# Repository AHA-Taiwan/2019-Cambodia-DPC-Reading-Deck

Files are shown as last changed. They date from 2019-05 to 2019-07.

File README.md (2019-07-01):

# 2019-Cambodia-DPC-Reading-Deck 柬埔寨教室改造設計
>Humanitarian Architecture in Cambodia<br/>
>以人道建築宗旨出發，由台灣交通大學服務學習中心、全球公民教育中心發起，與柬埔寨DPC小學、家扶中心合作規劃。使用自然材料、就地取材為原則，由交大建築所策劃義築設計、大安高工進行實作測試與志工培訓，設計規劃一個可容納約30名師生使用，離地抬高20至200公分並錯落配置的木鐵混構閱讀及活動平台。<br/>

## 基地環境：<br/>
位於柬泰邊境聚落，木材使用未加工原木，設計時宜需注意材料含濕變形，以及後續防潮防蝕保護等。<br/>
* 基地環境氣象資料：http://worldweather.wmo.int/tc/home.html <br/>
* 氣象觀測歷史紀錄：http://worldweather.wmo.int/tc/city.html?cityId=347 <br/>
* Google Map 位置：https://goo.gl/maps/Xri239yRok2xkyNN6  <br/>

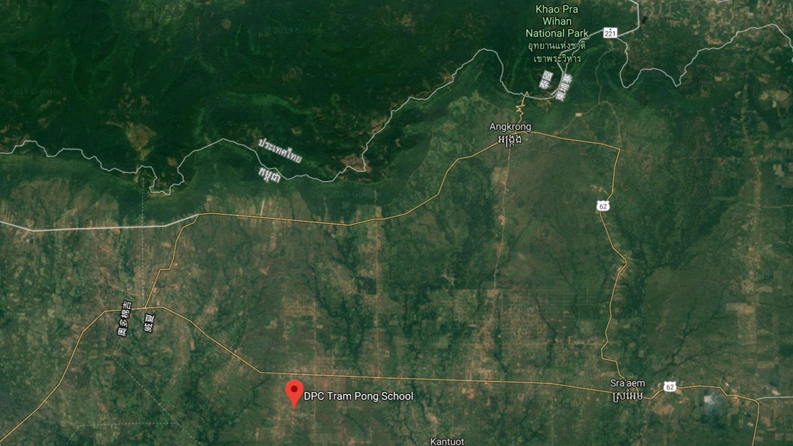
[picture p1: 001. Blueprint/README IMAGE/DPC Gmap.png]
Google Map

***
## 專案介紹：<br/>
* 主要建材：方鐵管[7.5x7.5x600cm(厚1.5mm)]、扁鐵管[4x8x600cm(厚1.5mm)]、原木板[2x25x400cm]、柬埔寨紅磚[8x8x17.5cm]等。
* 初勘簡介［影像紀錄］：https://reurl.cc/dkb1D
* 設計概述［影像紀錄］：https://reurl.cc/yNbDE
* 臉書紀錄：https://www.facebook.com/nctuasean/ 
* 數位模型［整體建物3D］：https://skfb.ly/6KQvW<br/>
* 數位模型［木柱露出3D］：https://skfb.ly/6KQwq<br/>
* 數位模型［鋼構平台3D］：https://skfb.ly/6KQw9<br/>
* 數位模型［主梁未轉3D］：https://skfb.ly/6LGSy<br/>
* 數位模型［最終定案3D］：https://skfb.ly/6LHYw<br/>

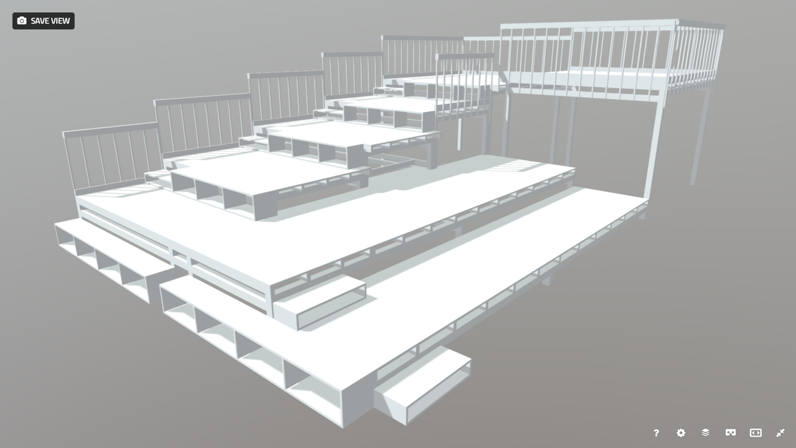
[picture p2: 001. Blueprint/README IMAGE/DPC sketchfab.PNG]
3D Model

<br/>
<br/>
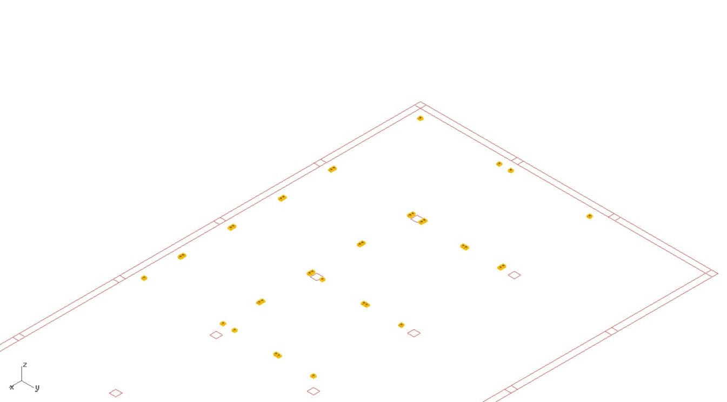
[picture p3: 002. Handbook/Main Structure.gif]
Main 20Structure.gif

<br/>
<br/>
***
## 如何達成合作建造：<br/>
* 請參閱［初次合作建造就上手 Collab-Const-Quick-Guide］：<br/>
https://github.com/AHA-Taiwan/Collab-Const-Quick-Guide/wiki <br/>
***
## 確保工作安全：<br/>
* 請參閱［合作建造-安全規範 Collab-Const-Safety］：<br/>
https://github.com/AHA-Taiwan/Collab-Const-Safety/wiki <br/>
***
## 探索合作資源：<br/>
* 請參閱［合作建造-資源探索 Collab-Const-Source］：<br/>
https://github.com/AHA-Taiwan/Collab-Const-Source/wiki <br/>
***
## 取得建造知識：<br/>
* 關於一般的常用構造技術（Techniques），請參閱［合作建造-學習知識 Collab-Const-Learning］：<br/>
https://github.com/AHA-Taiwan/Collab-Const-Learning/wiki <br/>
* 關於本案的特殊構築技術（Tectonic）， 請參閱［本案資料夾 002. Handbook］：<br/>
https://github.com/AHA-Taiwan/2019-Cambodia-DPC-Reading-Deck/tree/master/002.%20Handbook <br/>
***

> #### 歡迎參與專案開發，Branch合併可向專案管理者提出請求

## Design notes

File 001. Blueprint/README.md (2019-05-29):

CAD & 3D Simulation
更新設計圖請使用：

日期為檔名(ex:設計圖20190524.001) 
請在更新資料後於Commit changes做註解(ex:新增空心磚；修改柱位；刪除盪鞦韆設計)

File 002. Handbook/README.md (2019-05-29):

Handbook
更新施工手冊圖資請使用：

日期為檔名(ex:施工手冊 20190524.001)<br/>
請在更新資料後於Commit changes做註解(ex:新增空心磚；修改柱位；刪除盪鞦韆設計)

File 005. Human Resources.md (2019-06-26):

# 專業者佈局與人力成本紀錄 
主要紀錄整體施工過程中，專業者、準專業者、非專業者於不同工項所花費時數，從中可間接推估建造施工人力經費及時間成本。
專業者M、準專業者P、非專業者N，當地人加註C

## 一、鐵構施工
|人力編碼|當地人|工作總時數(hrs)|請工|換工|志工|
|:-:|:-:|:-:|:-:|:-:|:-:|
|MC01 |V |24 |V | |  |
|MC02 |V |24 |V | |  |
|MC02 |V |24 |V | |  |
|M01 | |16 | | |V |
|M02 | |16 | | |V |
|P01 | |16 | | |V |
|P02 | |16 | | |V |
***
## 二、矮牆砌磚
|人力編碼|當地人|工作總時數(hrs)|請工|換工|志工|
|:-:|:-:|:-:|:-:|:-:|:-:|
|M01 | |16 | | |V |
|P01 | |24 | | |V |
|P02 | |08 | | |V |
|N01 | |08 | | |V |
|N02 | |08 | | |V |
***
## 三、木地板加工
|人力編碼|當地人|工作總時數(hrs)|請工|換工|志工|
|:-:|:-:|:-:|:-:|:-:|:-:|
|M01 | |16 | | |V |
|P01 | |24 | | |V |
|P02 | |08 | | |V |
|N01 | |08 | | |V |
|N02 | |08 | | |V |
***
## 四、木扶手施工
|人力編碼|當地人|工作總時數(hrs)|請工|換工|志工|
|:-:|:-:|:-:|:-:|:-:|:-:|
|M01 | |16 | | |V |
|P01 | |24 | | |V |
|P02 | |08 | | |V |
|N01 | |08 | | |V |
|N02 | |08 | | |V |
***
## 五、木椅板固定於矮牆
|人力編碼|當地人|工作總時數(hrs)|請工|換工|志工|
|:-:|:-:|:-:|:-:|:-:|:-:|
|M01 | |16 | | |V |
|P01 | |24 | | |V |
|P02 | |08 | | |V |
|N01 | |08 | | |V |
|N02 | |08 | | |V |
***
## 六、木地板固定於受釘梁
|人力編碼|當地人|工作總時數(hrs)|請工|換工|志工|
|:-:|:-:|:-:|:-:|:-:|:-:|
|M01 | |16 | | |V |
|P01 | |24 | | |V |
|P02 | |08 | | |V |
|N01 | |08 | | |V |
|N02 | |08 | | |V |
***
## 七、木扶手固定於主梁
|人力編碼|當地人|工作總時數(hrs)|請工|換工|志工|
|:-:|:-:|:-:|:-:|:-:|:-:|
|M01 | |16 | | |V |
|P01 | |24 | | |V |
|P02 | |08 | | |V |
|N01 | |08 | | |V |
|N02 | |08 | | |V |
***
## 八、木地板收尾封邊
|人力編碼|當地人|工作總時數(hrs)|請工|換工|志工|
|:-:|:-:|:-:|:-:|:-:|:-:|
|M01 | |16 | | |V |
|P01 | |24 | | |V |
|P02 | |08 | | |V |
|N01 | |08 | | |V |
|N02 | |08 | | |V |
***
## 九、木書櫃施工
|人力編碼|當地人|工作總時數(hrs)|請工|換工|志工|
|:-:|:-:|:-:|:-:|:-:|:-:|
|M01 | |16 | | |V |
|P01 | |24 | | |V |
|P02 | |08 | | |V |
|N01 | |08 | | |V |
|N02 | |08 | | |V |
***

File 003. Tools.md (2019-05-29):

# 工具清單與故障維修紀錄 
主要紀錄整體施工過程中，所有使用之工具名稱、規格、數量、單位、廠牌、工具來源、維修紀錄(日期)等，從中可間接推估工具數量及機具購買或租借成本。

## 安全工具 
|編碼|工具名稱|規格|數量|單位|廠牌|工具來源|維修紀錄|
|:-:|:-:|:-:|:-:|:-:|:-:|:-:|:-:|
|SS001|安全帽|工地用|15|頂|一般|AHATLx5&大安x10|無|
|SS002|安全繩|傘背式|6|件|一般|AHA TL|無|
|SS003|護目鏡|8M|15|支|一般|AHA TL|無|
|SS004|口罩|M8|60|個|一般|AHA TL|無|
|SS005|手套|M8|60|雙|一般|AHA TL|無|

## 手工具 
|編碼|工具名稱|規格|數量|單位|廠牌|工具來源|維修紀錄|
|:-:|:-:|:-:|:-:|:-:|:-:|:-:|:-:|
|HT001|圓鍬|不鏽鋼|3|把|一般|AHA TL|無|
|HT002|方鏟|不鏽鋼|3|把|一般|AHA TL|無|
|HT003|捲尺|8M|5|把|一般|AHA TL|毀損報廢x1|
|HT004|萬能板手|M8|12|把|一般|AHA TL|無|
|HT005|棘輪板手|M8|12|把|一般|AHA TL|無|
|HT006|十字起子|一般|6|把|一般|AHATL|無|
|HT007|尖嘴鉗|一般|3|把|一般|AHATL|無|
|HT008|老虎鉗|一般|3|把|一般|AHATL|無|
|HT009|墨斗&墨汁|一般|1|組|一般|AHATL|墨汁用盡|
|HT010|水線|一般|1|捆|一般|AHATL|無|
|HT011|直角尺|中|6|把|一般|AHATL|無|
|HT012|鐵鎚|一般|3|把|一般|AHATL|毀損修復x1(20130824)|

## 電動工具 
|編碼|工具名稱|規格|數量|單位|廠牌|工具來源|維修紀錄|
|:-:|:-:|:-:|:-:|:-:|:-:|:-:|:-:|
|PT001|手持線鋸機|GST 8000 E|2|台|BOSCH|AHA TL|無|
|PT002|手持砂輪機|GWS 7-100|2|台|BOSCH|AHA TL|無|
|PT003|懸臂式鑽床|立式|1|台|一般|大安|無|
|PT004|手持式電鑽|BOSCH|3|把|BOSCH|AHA TL|無|
|PT005|手持式電鑽|BL 1013|2|把|MAKITA|AHA TL|無|
|PT006|電動拋光機|MT920|2|台|MAKITA|AHATL|無|
|PT007|修邊機|MT370|2|台|MAKITA|AHATL|無|

## 氣動工具 
|編碼|工具名稱|規格|數量|單位|廠牌|工具來源|維修紀錄|
|:-:|:-:|:-:|:-:|:-:|:-:|:-:|:-:|
|AT001|空壓機|E35 3.5HP|1|台|士東|AHA TL|無|
|AT002|氣動拋光機|RC5|3|台|士東|AHA TL|無|
|AT003|轉接頭|三叉|1|個|一般|AHA TL|無|
|AT004|延長氣管|8M|1|條|一般|AHA TL|無|

## 輔助工具 
|編碼|工具名稱|規格|數量|單位|廠牌|工具來源|維修紀錄|
|:-:|:-:|:-:|:-:|:-:|:-:|:-:|:-:|
|FS001|動力延長線|100M|2|座|一般|AHA TL|無|
|FS002|地燈|一般|8|個|一般|AHA TL|無|
|FS003|工作燈|一般|8|個|一般|AHA TL|無|
|FS004|鷹架|一般|6|座|一般|富山國小|無|
|FS005|鋁梯|120|2|座|一般|富山國小|無|
|FS006|工具箱|一般|2|個|一般|AHA TL|無|

## 工具耗材 
|編碼|工具名稱|規格|數量|單位|廠牌|工具來源|維修紀錄|
|:-:|:-:|:-:|:-:|:-:|:-:|:-:|:-:|
|TC001|木工鑽尾|3mm|4|支|一般|AHA TL|無|
|TC002|木工鑽尾|10mm|4|支|一般|AHA TL|無|
|TC003|金屬鑽尾|10mm|4|支|一般|AHA TL|無|
|TC004|電鑽套筒|19號|2|支|一般|AHA TL|無|
|TC005|圓形砂紙|100號|50|張|一般|AHA TL|無|
|TC006|砂紙|100號|50|張|一般|AHA TL|無|
|TC007|線鋸刀片|T101B|10|片|BOSCH|AHA TL|無|
|TC008|地燈管|鹵素燈500W|10|個|一般|AHA TL|無|
|TC009|工作燈泡|60W|10|個|一般|AHA TL|無|
|TC010|砂輪片|磨(厚片)|5|片|一般|AHA TL|無|
|TC011|砂輪片|切(細片)|5|片|一般|AHA TL|無|

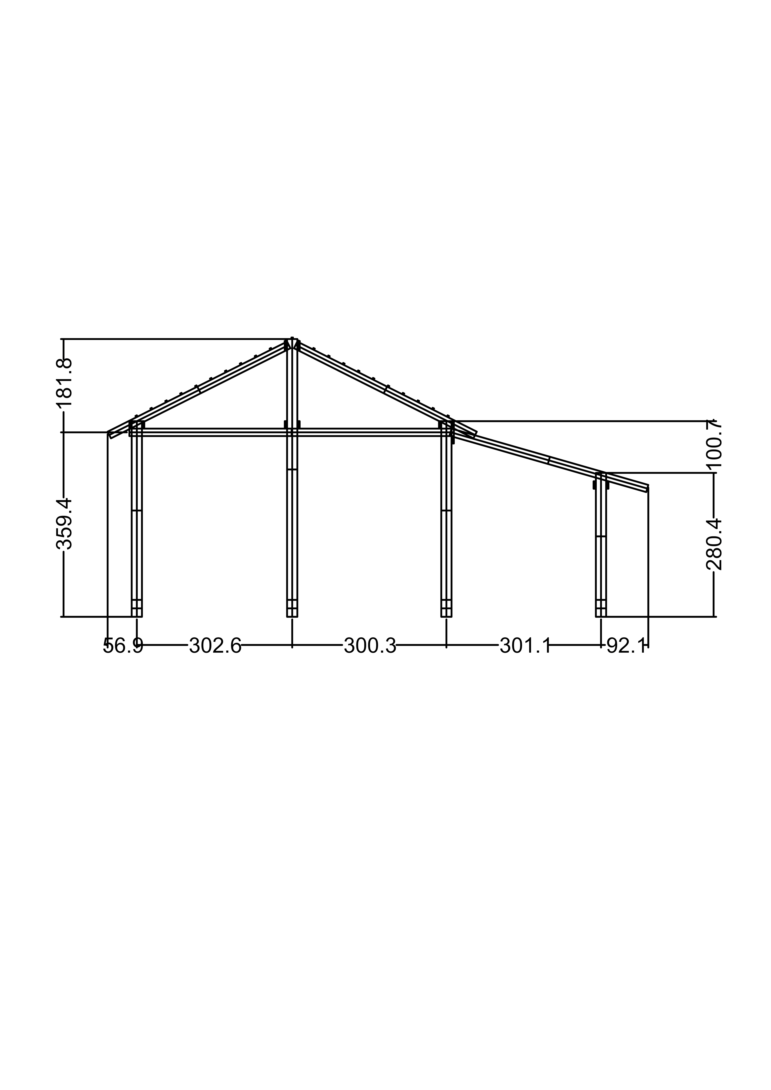
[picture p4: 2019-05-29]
001. Blueprint/3D model/20190116 第一次測繪3D檔/front.jpg

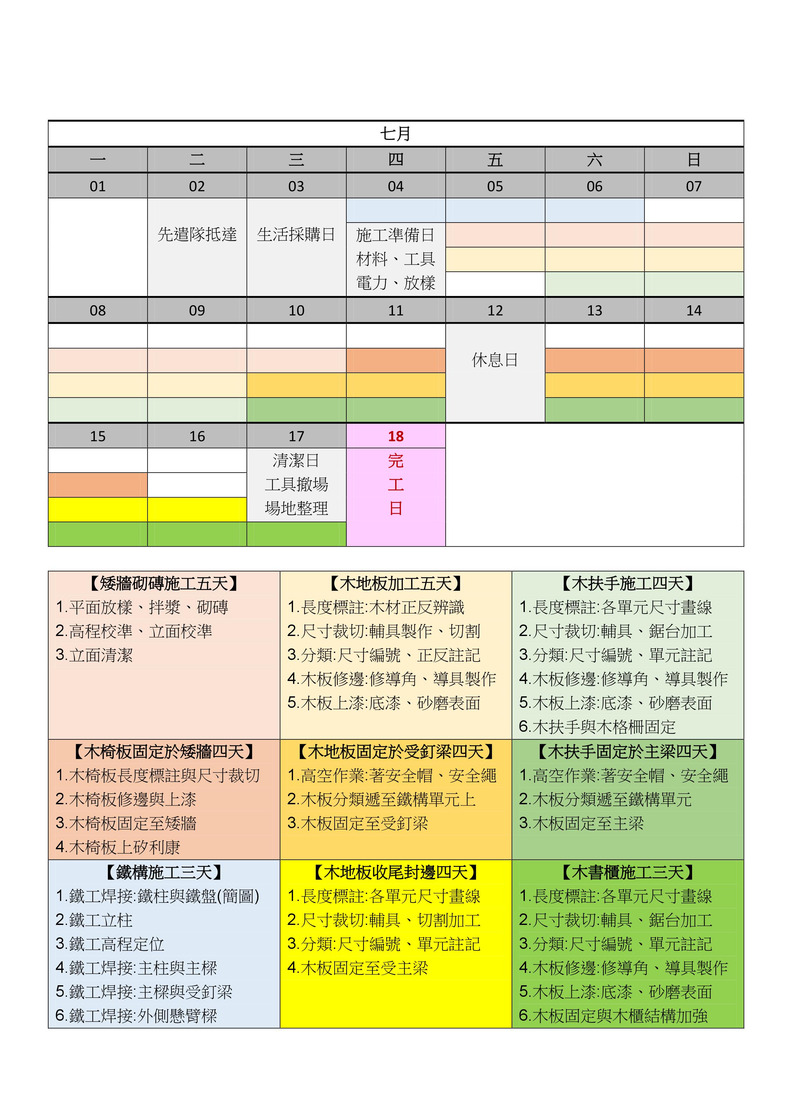
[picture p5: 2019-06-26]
002. Handbook/Work Processes.jpg

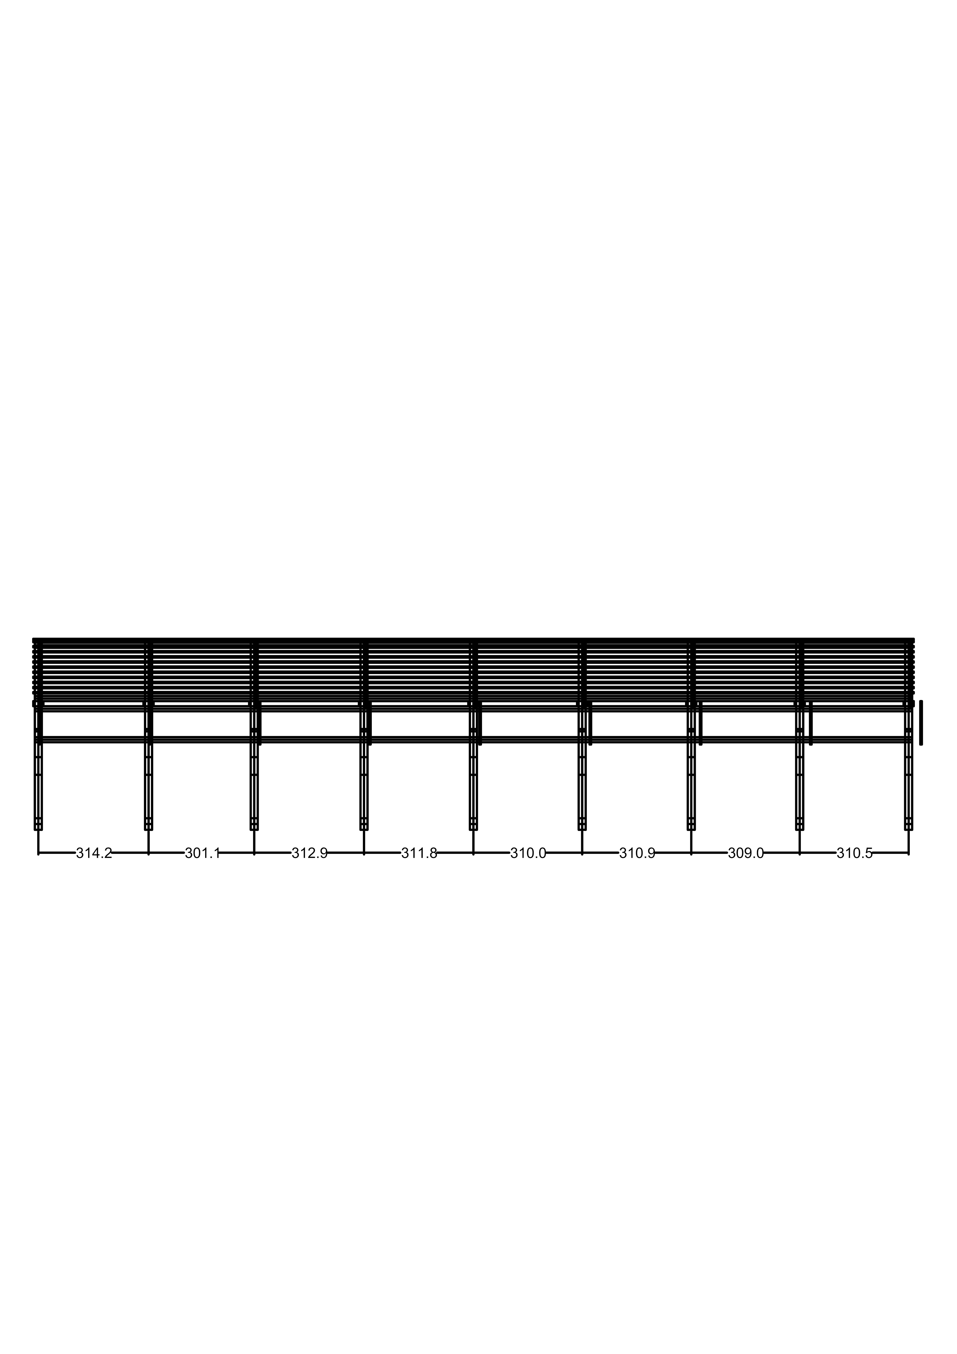
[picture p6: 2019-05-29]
001. Blueprint/3D model/20190116 第一次測繪3D檔/right.jpg

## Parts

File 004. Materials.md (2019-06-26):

# 材料清單與部件編碼紀錄 
主要紀錄整體施工過程中，各部位構件之材料名稱、規格、數量、單價、材料來源、廠商資訊等，從中可推估材料經費及運輸成本。

## 主要建材（柬埔寨）
|編碼|材料名稱|部件位置|規格|單價(鎂)|數量|材料來源|參考資訊|
|:-:|:-:|:-:|:-:|:-:|:-:|:-:|:-:|
|F001|原木板|地板、椅櫃扶手|1片2x25x400cm，1m³=50片|250|4m³|OM|[金邊家扶](https://reurl.cc/1AaA8)|
|F002|方鐵管|基礎、主結構體|7.5x7.5x600cm(厚1.5mm)|17|22|OM|[金邊家扶](https://reurl.cc/1AaA8)|
|F003|扁鐵管|基礎、主結構體|4x8x600cm(厚1.5mm)|12.5|27|OM|[金邊家扶](https://reurl.cc/1AaA8)|
|F004|長磚|外側牆|8x8x17.5cm|0.065|2900|OM|[金邊家扶](https://reurl.cc/1AaA8)|
|F005|扁磚|外側牆|4x4x17.5cm|0.075|100|OM|[金邊家扶](https://reurl.cc/1AaA8)|
|F006|水泥|基礎、外側牆|1tones|103|1|OM|[金邊家扶](https://reurl.cc/1AaA8)|
|F007|砂|基礎、外側牆|1m³|20|3|OM|[金邊家扶](https://reurl.cc/1AaA8)|

<br/>備註［原木板］：1m³=50 pices  The size of the wood is 2cm*25cm*400cm. The amount of purchaing is 1m³. We still can buy 120 pieces. TFCF Cambodia will negociate with the shop keep the price the same. 購買以1立方米為單位，如若以單片計算價錢可能會不一樣<br/>
***
## 五金材料（台灣準備）
|編碼|材料名稱|部件位置|規格|單價(元)|數量|材料來源|參考資訊|
|:-:|:-:|:-:|:-:|:-:|:-:|:-:|:-:|
|A001|自攻螺絲|結構體及木板間|1.5"|0.5|4500|[應弘](http://ih.kong.tw/)|https://reurl.cc/o2lA3|
|A002|黑木螺絲|木板間|2"|0.8|3800|[應弘](http://ih.kong.tw/)|https://reurl.cc/o2lA3|
|A003|黑木螺絲|木板間|1.5"|0.6|1000|[應弘](http://ih.kong.tw/)|https://reurl.cc/o2lA3|
|A004|黑木螺絲|木板間|2.5"|1.2|1000|[應弘](http://ih.kong.tw/)|https://reurl.cc/o2lA3|
|A005|不鏽鋼芽條|外側牆|304不鏽鋼M6長度1M(直徑6mm)|50|30|[應弘](http://ih.kong.tw/)|https://reurl.cc/o2lA3|
|A006|不鏽鋼墊片|外側牆|直徑6mm|0.9|240|[應弘](http://ih.kong.tw/)|https://reurl.cc/o2lA3|
|A007|不鏽鋼螺帽|外側牆|直徑8mm|0.9|240|[應弘](http://ih.kong.tw/)|https://reurl.cc/o2lA3|
|A008|鐵釘|木板間|1"(斤計)|30|2|[應弘](http://ih.kong.tw/)|https://reurl.cc/o2lA3|
|A009|鐵釘|木板間|2"(斤計)|30|4|[應弘](http://ih.kong.tw/)|https://reurl.cc/o2lA3|
|A010|鐵釘|木板間|2.5"(斤計)|30|4|[應弘](http://ih.kong.tw/)|https://reurl.cc/o2lA3|
***

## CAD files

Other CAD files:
001. Blueprint/3D model/20190116 第一次測繪3D檔/0113草模.3dm
001. Blueprint/3D model/20190116 第一次測繪3D檔/0116_darren草模.3dm
001. Blueprint/3D model/20190517 侯老師--DPC校長與基地3D/Dining Hall.skp
001. Blueprint/3D model/20190517 侯老師--DPC校長與基地3D/people.skp
001. Blueprint/3D model/20190626 志工團做模型SKP檔案/0626 process.skp
001. Blueprint/3D model/20190630 定案SKP檔案/Dining-Hall0630.skp
001. Blueprint/3D model/20190701 最終定案版本【主梁、受釘梁轉向】/PLAYSTEPS.skp

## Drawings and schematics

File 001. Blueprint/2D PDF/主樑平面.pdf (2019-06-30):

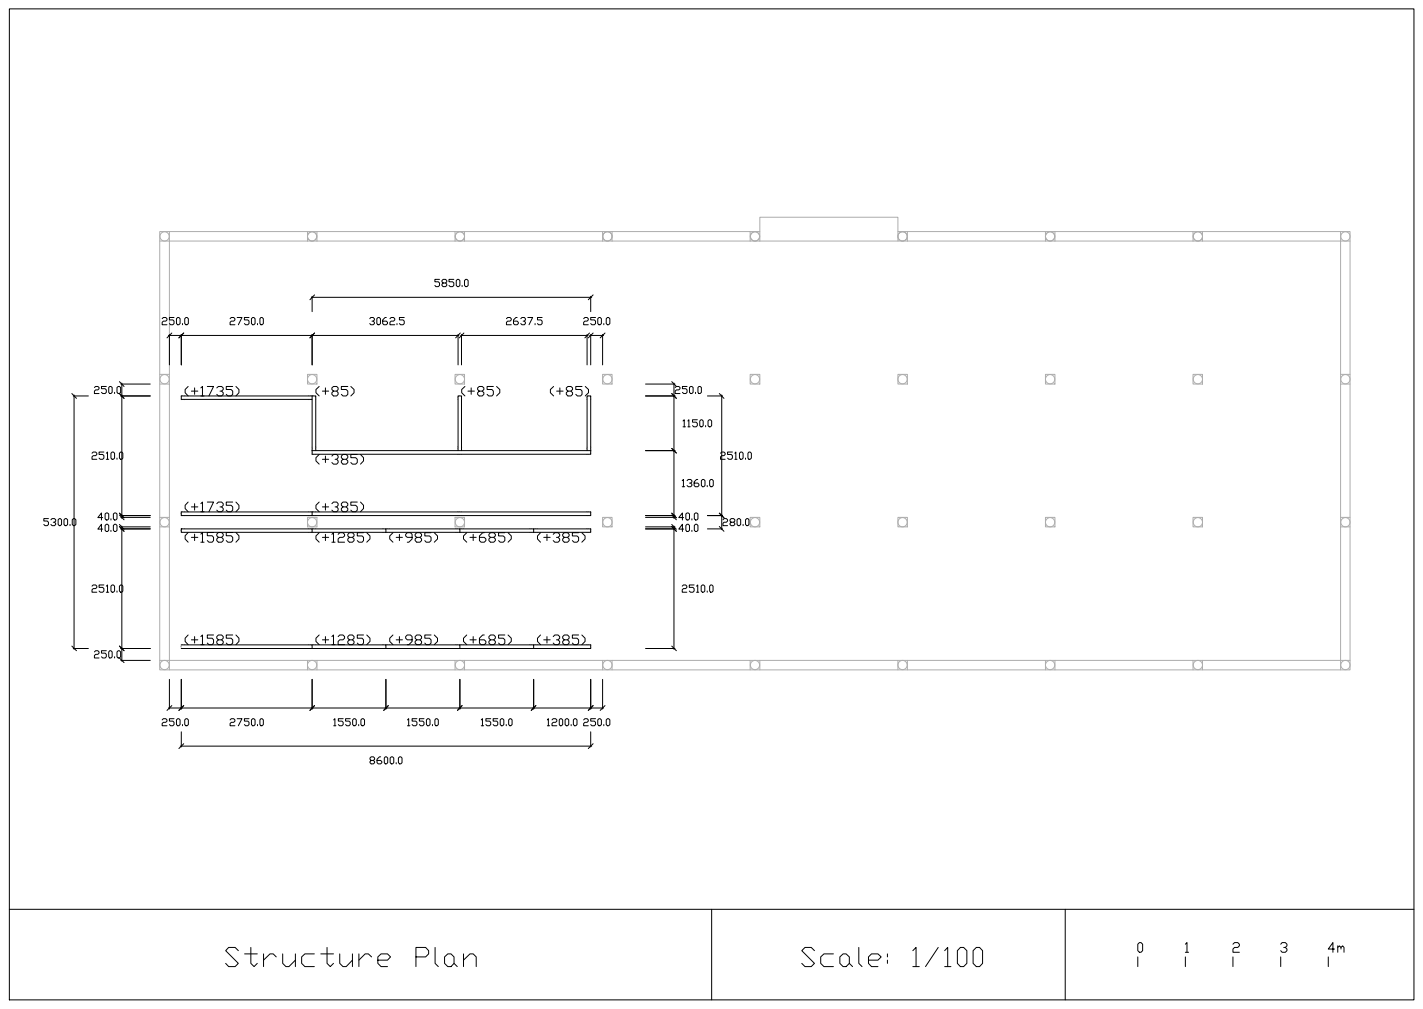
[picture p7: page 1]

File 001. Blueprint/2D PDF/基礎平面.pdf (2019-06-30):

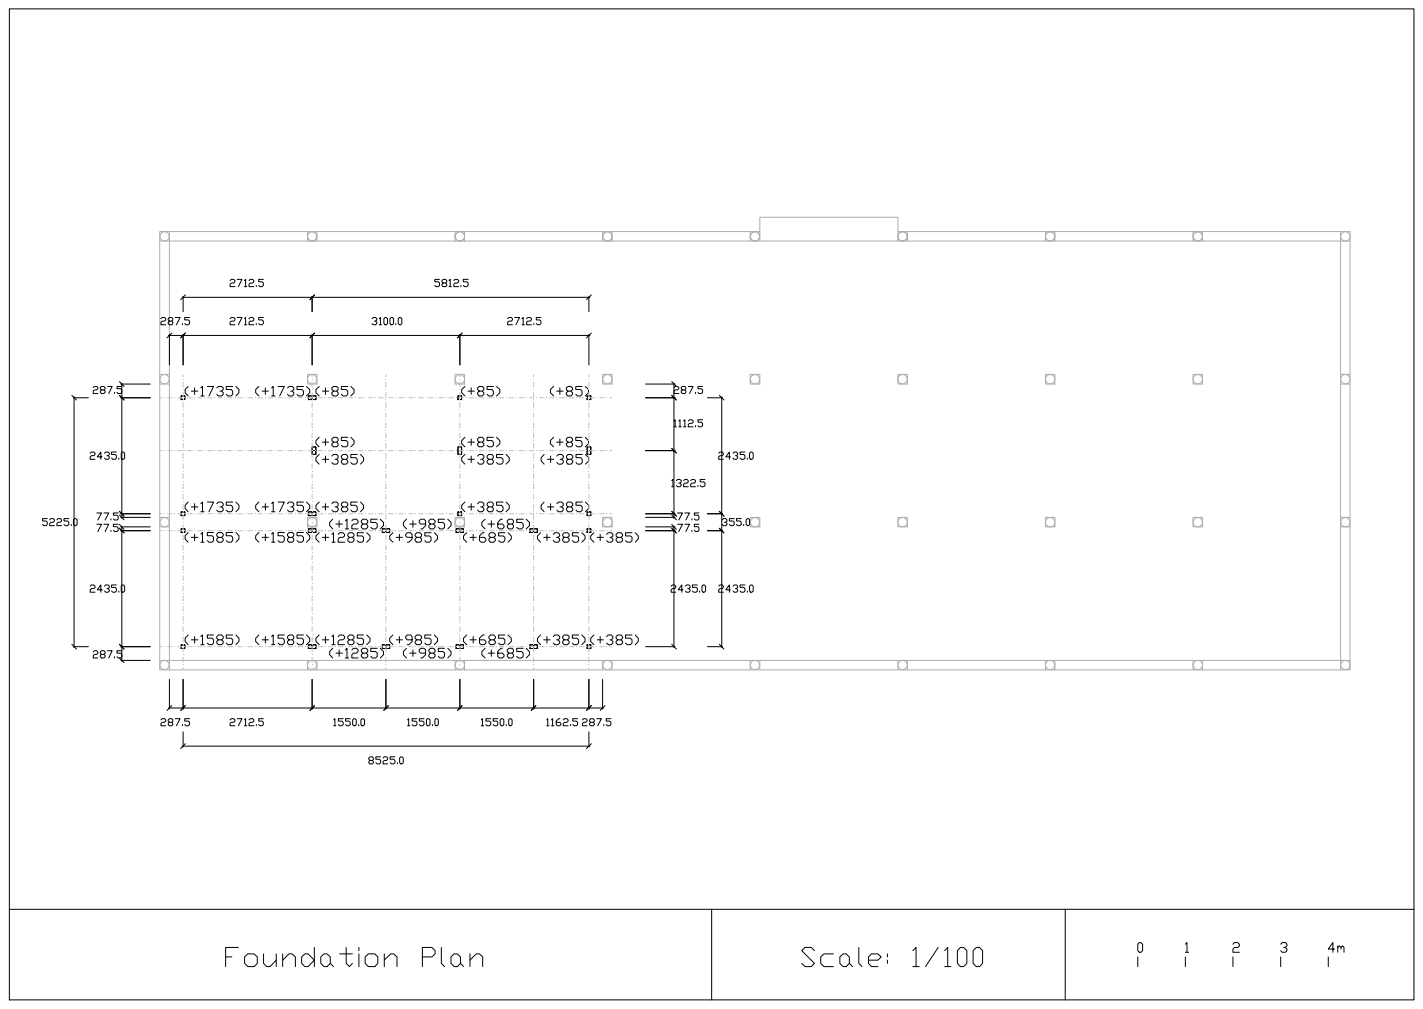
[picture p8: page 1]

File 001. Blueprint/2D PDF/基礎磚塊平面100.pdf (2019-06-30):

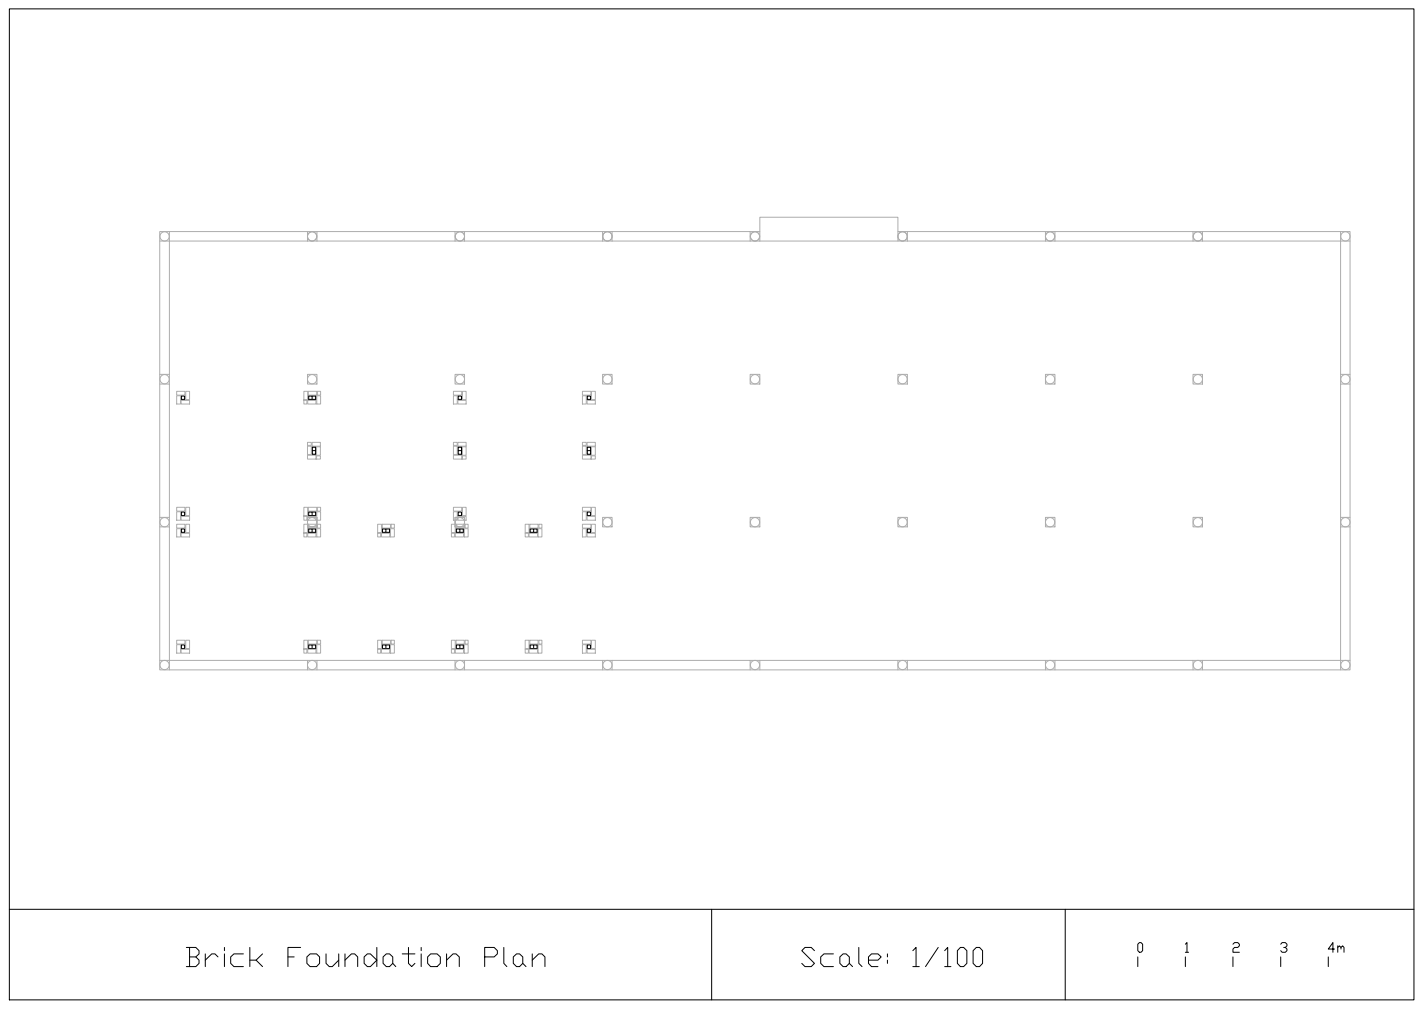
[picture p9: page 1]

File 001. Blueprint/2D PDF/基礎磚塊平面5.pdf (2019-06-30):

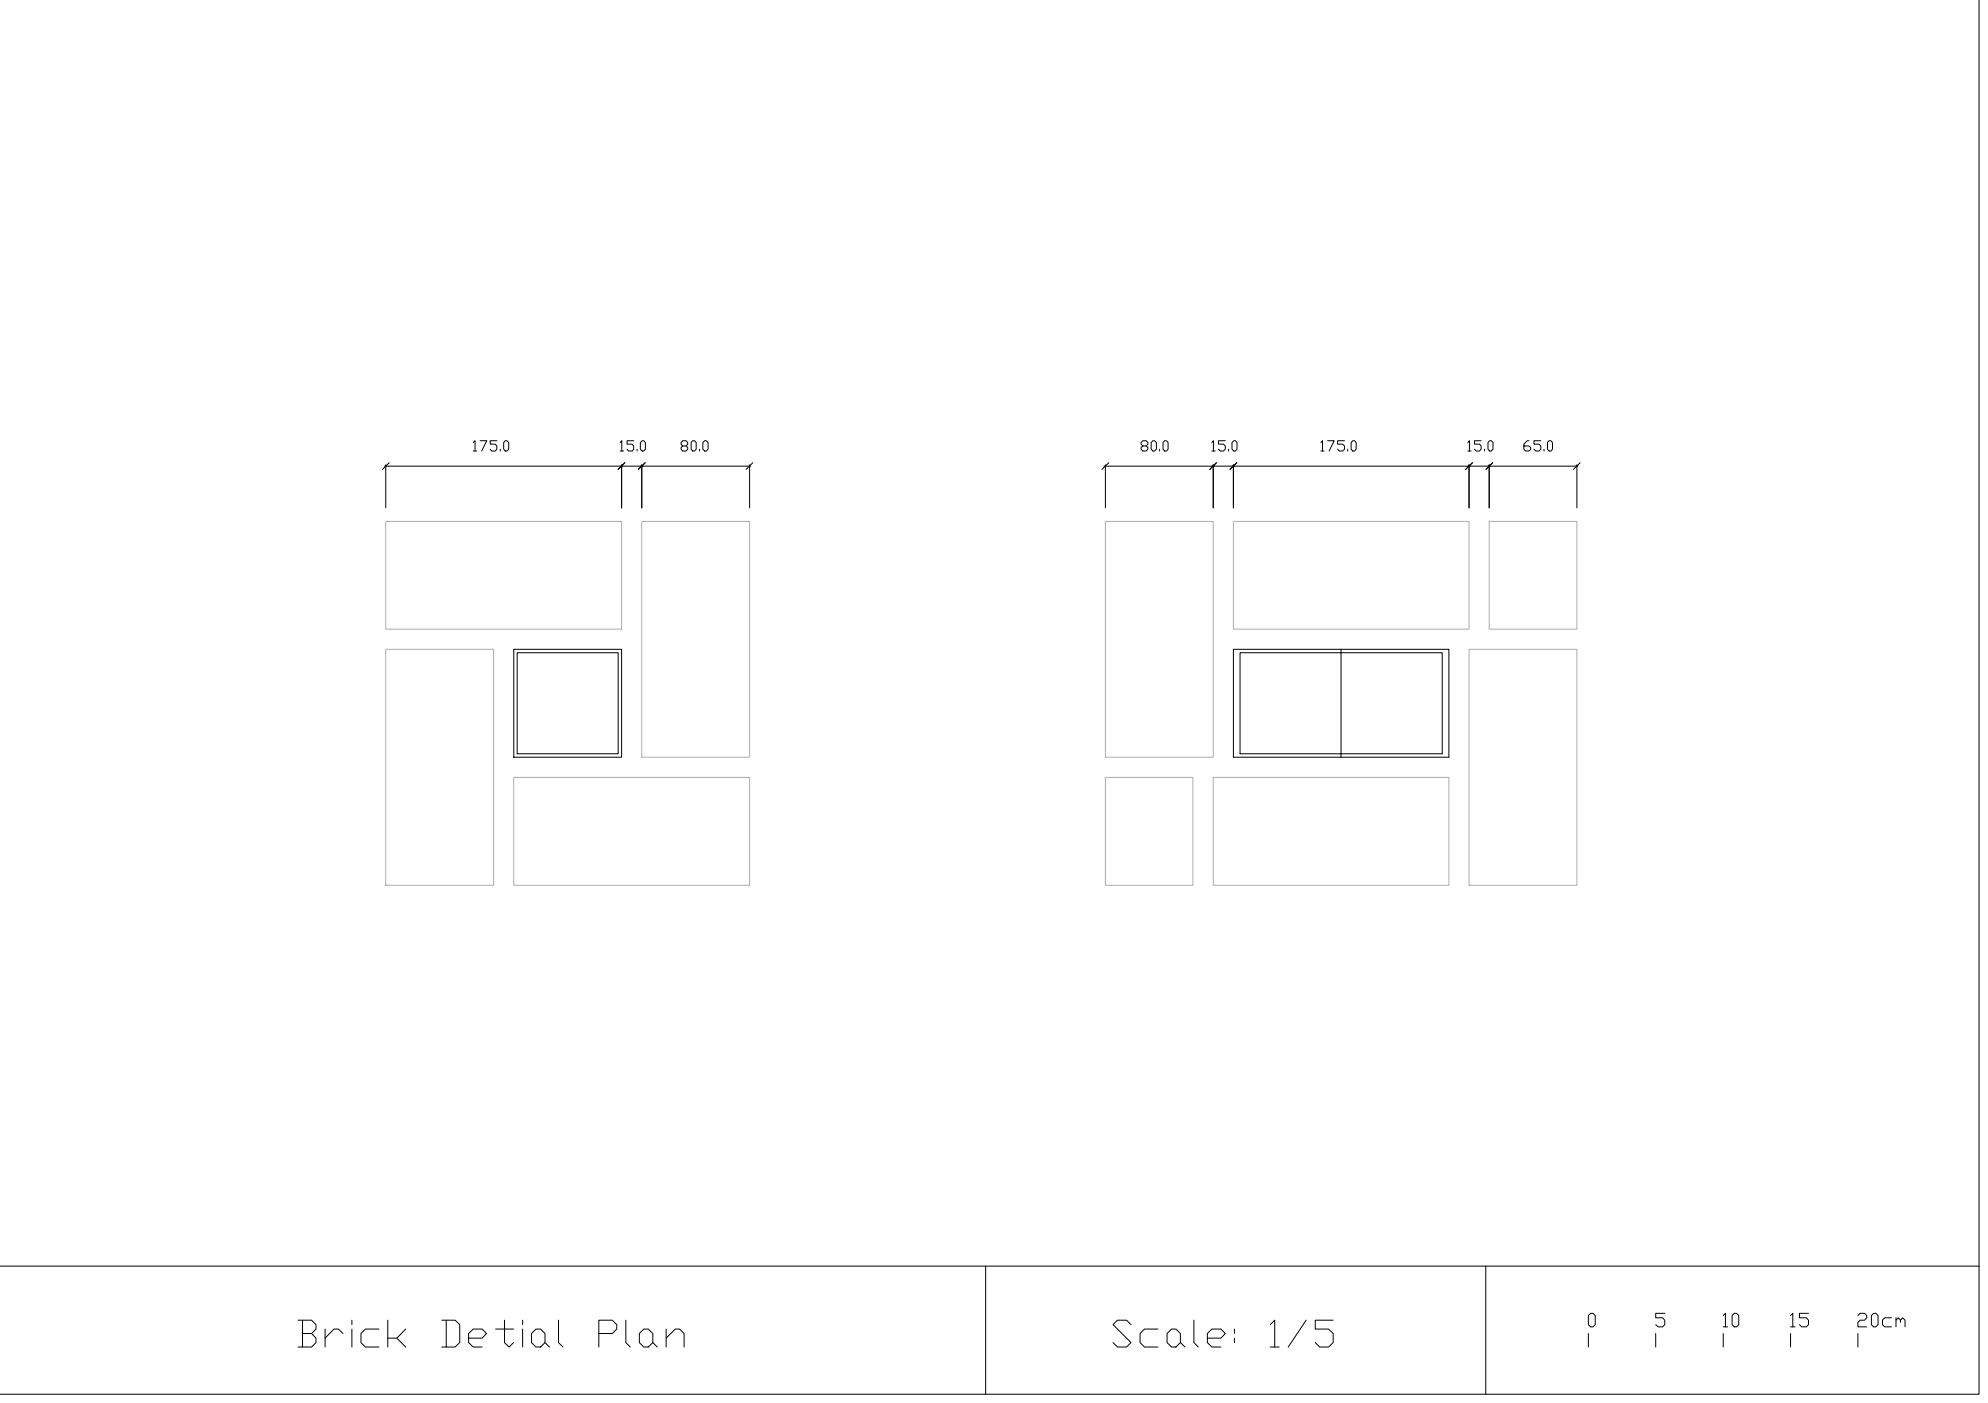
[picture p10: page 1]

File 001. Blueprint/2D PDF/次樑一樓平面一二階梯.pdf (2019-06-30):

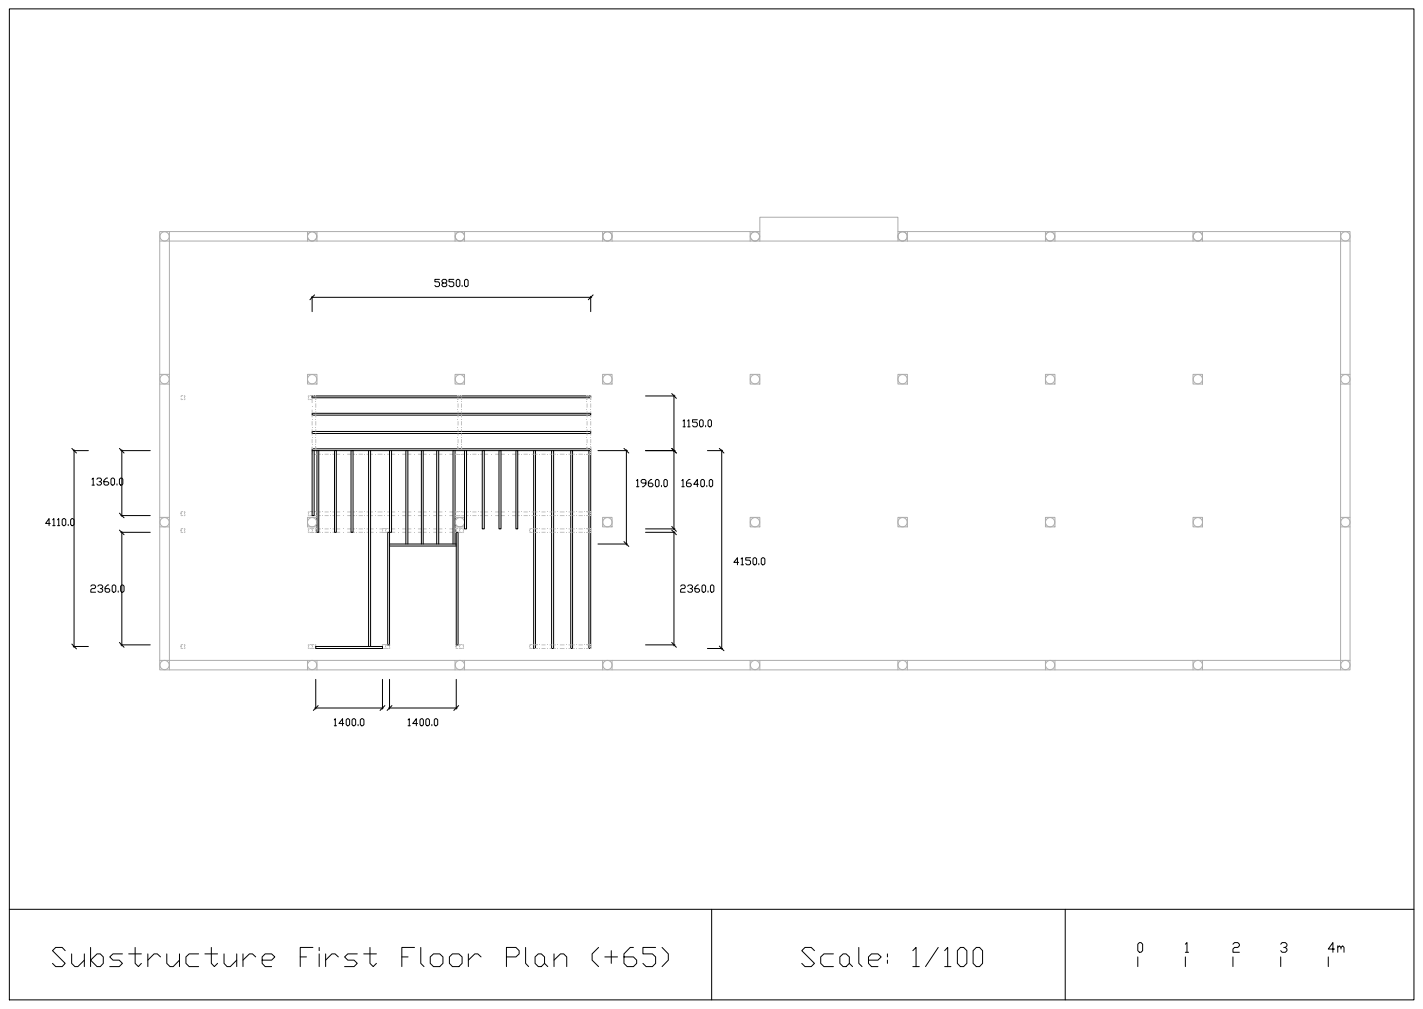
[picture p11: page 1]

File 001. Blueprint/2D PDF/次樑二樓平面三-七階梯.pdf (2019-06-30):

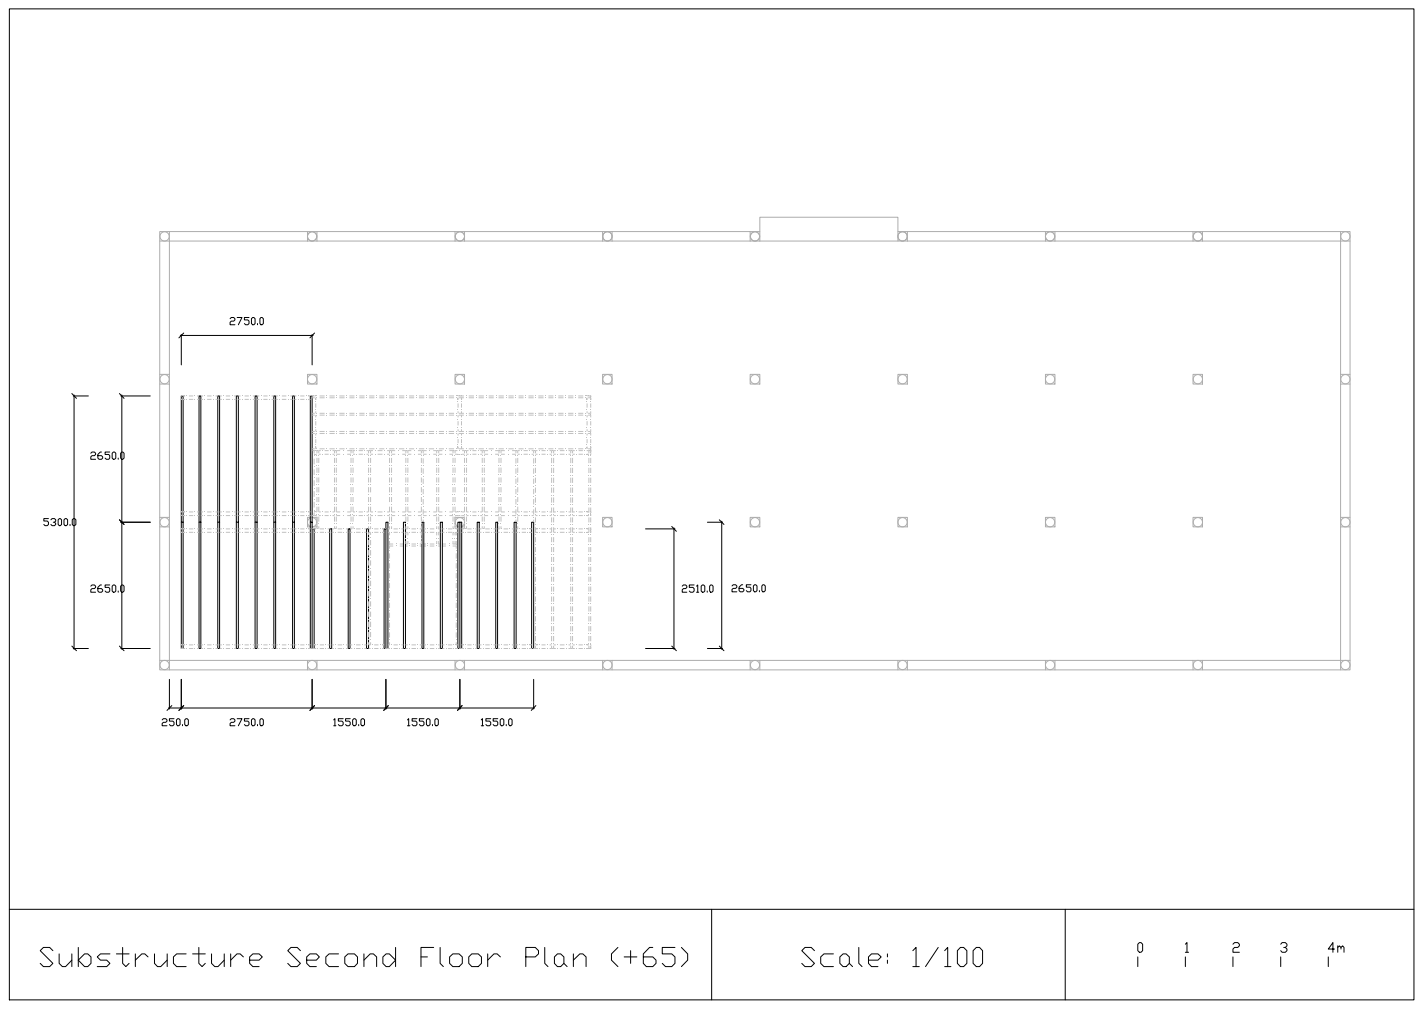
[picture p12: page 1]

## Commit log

2019-05-29 Create 003. Material.md
2019-05-29 Rename 003. Material.md to 004. Material.md
2019-05-29 +2019 1-5月設計發展3D
    +2019 1-5月設計發展3D
    [0113草模.3dm, 0116_darren草模.3dm, Dining Hall.skp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]
2019-06-17 Rename 004. Material.md to 004. Materials.md
2019-06-26 -delete 2013 GIF sample
    -delete 2013 GIF sample
2019-06-26 Update 004. Materials.md
2019-06-26 +柬埔寨主要建材採購清單、台灣五金採購清單
2019-06-26 +柬埔寨主要工序、人力編碼
2019-06-26 +柬埔寨構築九大工項、人力編碼
    +柬埔寨構築九大工項、人力編碼
2019-06-30 +定案3dm&skp
    +定案3dm&skp
    [0626 process.skp, Dining-Hall0630.skp]
2019-06-30 +基礎放樣圖、受釘梁放樣圖、主梁配置圖
    +基礎放樣圖、受釘梁放樣圖、主梁配置圖
2019-07-01 +3dm, skp最終定案版本
    20190701 修改主梁、受釘梁轉向
    [PLAYSTEPS.skp]
2019-07-19 書櫃改成書桌
    書櫃改成書桌
